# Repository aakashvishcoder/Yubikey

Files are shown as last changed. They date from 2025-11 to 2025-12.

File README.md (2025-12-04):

# Yubikey

This is my version of a YubiKey, built around the RP2040 microcontroller! It’s a compact, secure authentication device designed to generate one‑time passwords and handle cryptographic operations for two‑factor authentication. This key has several unique features and components (as listed below), and is meant to replicate the core functionality of a hardware security token.

# Features:
- Programmable LED(s)
- USBC Receptacle
- RP2040 Microcontroller
- Stores Password (through firmware)

# How to Use

The switches on the PCB can be used to boot up and reset the microcontroller, and the firmware can be modified to your liking!

# Images:







# Build of Materials (BOM)
| Item | Description | Qty | Product link | Price w/ Tax ($) | Running Total |
|---|---|-----|---|---|---|
| Capacitor | 1uF | 2 | [link](https://jlcpcb.com/partdetail/53938-CL05A105KA5NQNC/C52923) | $0.03 | $0.03 |
| Capacitor | 0.1uF | 4 | [link](https://jlcpcb.com/partdetail/1877-CL05B104KO5NNNC/C1525) | $0.07 | $0.10 |
| Capacitor | 10uF | 1 | [link](https://jlcpcb.com/partdetail/2043-CL10A106MQ8NNNC/C1691) | $0.09 | $0.19 |
| Capacitor | 15pF | 2 | [link](https://jlcpcb.com/partdetail/1914-0402CG150J500NT/C1547) | $0.01 | $0.20 |
| Resistor | 5.1k | 2 | [link](https://jlcpcb.com/partdetail/26648-0402WGF5101TCE/C25905) | $0.01 | $0.21 |
| Resistor | 470 | 1 | [link](https://jlcpcb.com/partdetail/UNIROYAL-0402WGF4700TCE/C25130) | $0.01 | $0.22 |
| Resistor | 4.7k | 2 | [link](https://jlcpcb.com/partdetail/UNIROYAL-0402WGF4701TCE/C25867) | $0.01 | $0.23 |
| Resistor | 10k | 1 | [link](https://jlcpcb.com/partdetail/UNIROYAL-0402WGF1002TCE/C25744) | $0.01 | $0.24 |
| Resistor | 27 | 2 | [link](https://jlcpcb.com/partdetail/UNIROYAL-0402WGF270JTCE/C25100) | $0.01 | $0.25 |
| Resistor | 1k | 1 | [link](https://jlcpcb.com/partdetail/UNIROYAL-0402WGF1001TCE/C11702) | $0.01 | $0.26 |
| SW_Push | Tactile Button | 2 | [link](https://jlcpcb.com/partdetail/XKBConnectivity-TS-1187A-B-A-B/C318884) | $0.42 | $0.68 |
| LED | Indicator LED 0402 | 1 | [link](https://jlcpcb.com/partdetail/Honglitronic-HL-LED0402R/C2290) | $0.02 | $0.70 |
| WS2812B | RGB LED | 1 | [link](https://jlcpcb.com/partdetail/Worldsemi-WS2812B_BT/C2761795) | $0.20 | $0.90 |
| RP2040 | Microcontroller | 1 | [link](https://jlcpcb.com/partdetail/RaspberryPi-RP2040/C2040) | $4.58 | $5.48 |
| USB Receptacle | USB-C 16P | 1 | [link](https://jlcpcb.com/partdetail/Korean_HropartsElec-TYPE_C_31_M12/C165948) | $0.85 | $6.33 |
| ATECC608A | Secure Element | 1 | [link](https://jlcpcb.com/partdetail/MicrochipTech-ATECC608ASSHDA/C148118) | $1.97 | $8.30 |
| W25Q128JVS | Flash Storage | 1 | [link](https://jlcpcb.com/partdetail/WinbondElec-W25Q128JVSIQ/C97521) | $2.67 | $10.97 |
| Crystal | 12MHz 3225 | 1 | [link](https://jlcpcb.com/partdetail/YXC_CrystalOscillators-X322512MSB4SI/C9002) | $0.32 | $11.29 |
| Conn_01x03 | Pin Header 1x3 | 1 | [link](https://jlcpcb.com/partdetail/BOOMELE-BM03B-SRSS-TB/C42431804) | $0.05 | $11.34 |
| Conn_01x20 | 1x20 Pin Headers | 2 | [link](https://jlcpcb.com/partdetail/BOOMELE-BM20B-SRSS-TB/C42431804) | $0.17 | $11.51 |
| Yubikey PCBA | PCBA board assembly | 1 | [link](https://cart.jlcpcb.com/) | $43.94 | $55.45 |

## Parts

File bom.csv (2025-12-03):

Item | Description | Quantity | Product link | Price w/ Tax ($) | Running Total
Capacitor | 1uF | 2 | https://jlcpcb.com/partdetail/53938-CL05A105KA5NQNC/C52923 | $0.03 | $0.03
Capacitor | 0.1uF | 4 | https://jlcpcb.com/partdetail/1877-CL05B104KO5NNNC/C1525 | $0.07 | $0.10
Capacitor | 10uF | 1 | https://jlcpcb.com/partdetail/2043-CL10A106MQ8NNNC/C1691 | $0.09 | $0.19
Capacitor | 15pF | 2 | https://jlcpcb.com/partdetail/1914-0402CG150J500NT/C1547 | $0.01 | $0.20
Resistor | 5.1k | 2 | https://jlcpcb.com/partdetail/26648-0402WGF5101TCE/C25905 | $0.01 | $0.21
Resistor | 470 | 1 | https://jlcpcb.com/partdetail/UNIROYAL-0402WGF4700TCE/C25130 | $0.01 | $0.22
Resistor | 4.7k | 2 | https://jlcpcb.com/partdetail/UNIROYAL-0402WGF4701TCE/C25867 | $0.01 | $0.23
Resistor | 10k | 1 | https://jlcpcb.com/partdetail/UNIROYAL-0402WGF1002TCE/C25744 | $0.01 | $0.24
Resistor | 27 | 2 | https://jlcpcb.com/partdetail/UNIROYAL-0402WGF270JTCE/C25100 | $0.01 | $0.25
Resistor | 1k | 1 | https://jlcpcb.com/partdetail/UNIROYAL-0402WGF1001TCE/C11702 | $0.01 | $0.26
SW_Push | Tactile Button | 2 | https://jlcpcb.com/partdetail/XKBConnectivity-TS-1187A-B-A-B/C318884 | $0.42 | $0.68
LED | Indicator LED 0402 | 1 | https://jlcpcb.com/partdetail/Honglitronic-HL-LED0402R/C2290 | $0.02 | $0.70
WS2812B | RGB LED | 1 | https://jlcpcb.com/partdetail/Worldsemi-WS2812B_BT/C2761795 | $0.20 | $0.90
RP2040 | Microcontroller | 1 | https://jlcpcb.com/partdetail/RaspberryPi-RP2040/C2040 | $4.58 | $5.48
USB Receptacle | USB-C 16P | 1 | https://jlcpcb.com/partdetail/Korean_HropartsElec-TYPE_C_31_M12/C165948 | $0.85 | $6.33
ATECC608A | Secure Element | 1 | https://jlcpcb.com/partdetail/MicrochipTech-ATECC608ASSHDA/C148118 | $1.97 | $8.30
W25Q128JVS | Flash Storage | 1 | https://jlcpcb.com/partdetail/WinbondElec-W25Q128JVSIQ/C97521 | $2.67 | $10.97
Crystal | 12MHz 3225 | 1 | https://jlcpcb.com/partdetail/YXC_CrystalOscillators-X322512MSB4SI/C9002 | $0.32 | $11.29
Conn_01x03 | Pin Header 1x3 | 1 | https://jlcpcb.com/partdetail/BOOMELE-BM03B-SRSS-TB/C42431804 | $0.05 | $11.34
Conn_01x20 | 1x20 Pin Headers | 2 | https://jlcpcb.com/partdetail/BOOMELE-BM20B-SRSS-TB/C42431804 | $0.17 | $11.51
Yubikey PCBA | PCBA board assembly | 1 | N/A (https://cart.jlcpcb.com/) | $43.94 | $55.45

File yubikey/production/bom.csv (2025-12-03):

Designator | Footprint | Quantity | Value | LCSC Part #
C1,C6 | 0402 | 2 | 1uF | C1523
C2,C3,C4,C9 | 0402 | 4 | 100nF | C1525
C5 | 0402 | 1 | 10uF | C15525
C7,C8 | 0402 | 2 | 15pF | C1547
D1 | 0402 | 1 | LED | C2290
J1 | USB_C_Receptacle_GCT_USB4105-xx-A_16P_TopMnt_Horizontal | 1 | USB_C_Receptacle_USB2.0_16P | C165948
R1,R2 | 0402 | 2 | 5.1k | C25905
R3 | 0402 | 1 | 470 | C25130
R4,R5 | 0402 | 2 | 4.7k | C25867
R6 | 0402 | 1 | 10k | C25804
R7,R8 | 0402 | 2 | 27 | C23154
R9 | 0402 | 1 | 1k | C21190
SW1 | SW_Tactile_SPST_NO_Straight_CK_PTS636Sx25SMTRLFS | 1 | BOOTSEC | C318884
SW2 | SW_Tactile_SPST_NO_Straight_CK_PTS636Sx25SMTRLFS | 1 | RESET | C318884
U1 | SOIC-8_3.9x4.9mm_P1.27mm | 1 | ATECC608A-SSHDA | C148118
U2 | QFN-56-1EP_7x7mm_P0.4mm_EP3.2x3.2mm | 1 | RP2040 | C2040
U3 | SOIC-8_5.3x5.3mm_P1.27mm | 1 | W25Q128JVS | C97521
Y1 | Crystal_SMD_Abracon_ABM8G-4Pin_3.2x2.5mm | 1 | 12MHz | C9005

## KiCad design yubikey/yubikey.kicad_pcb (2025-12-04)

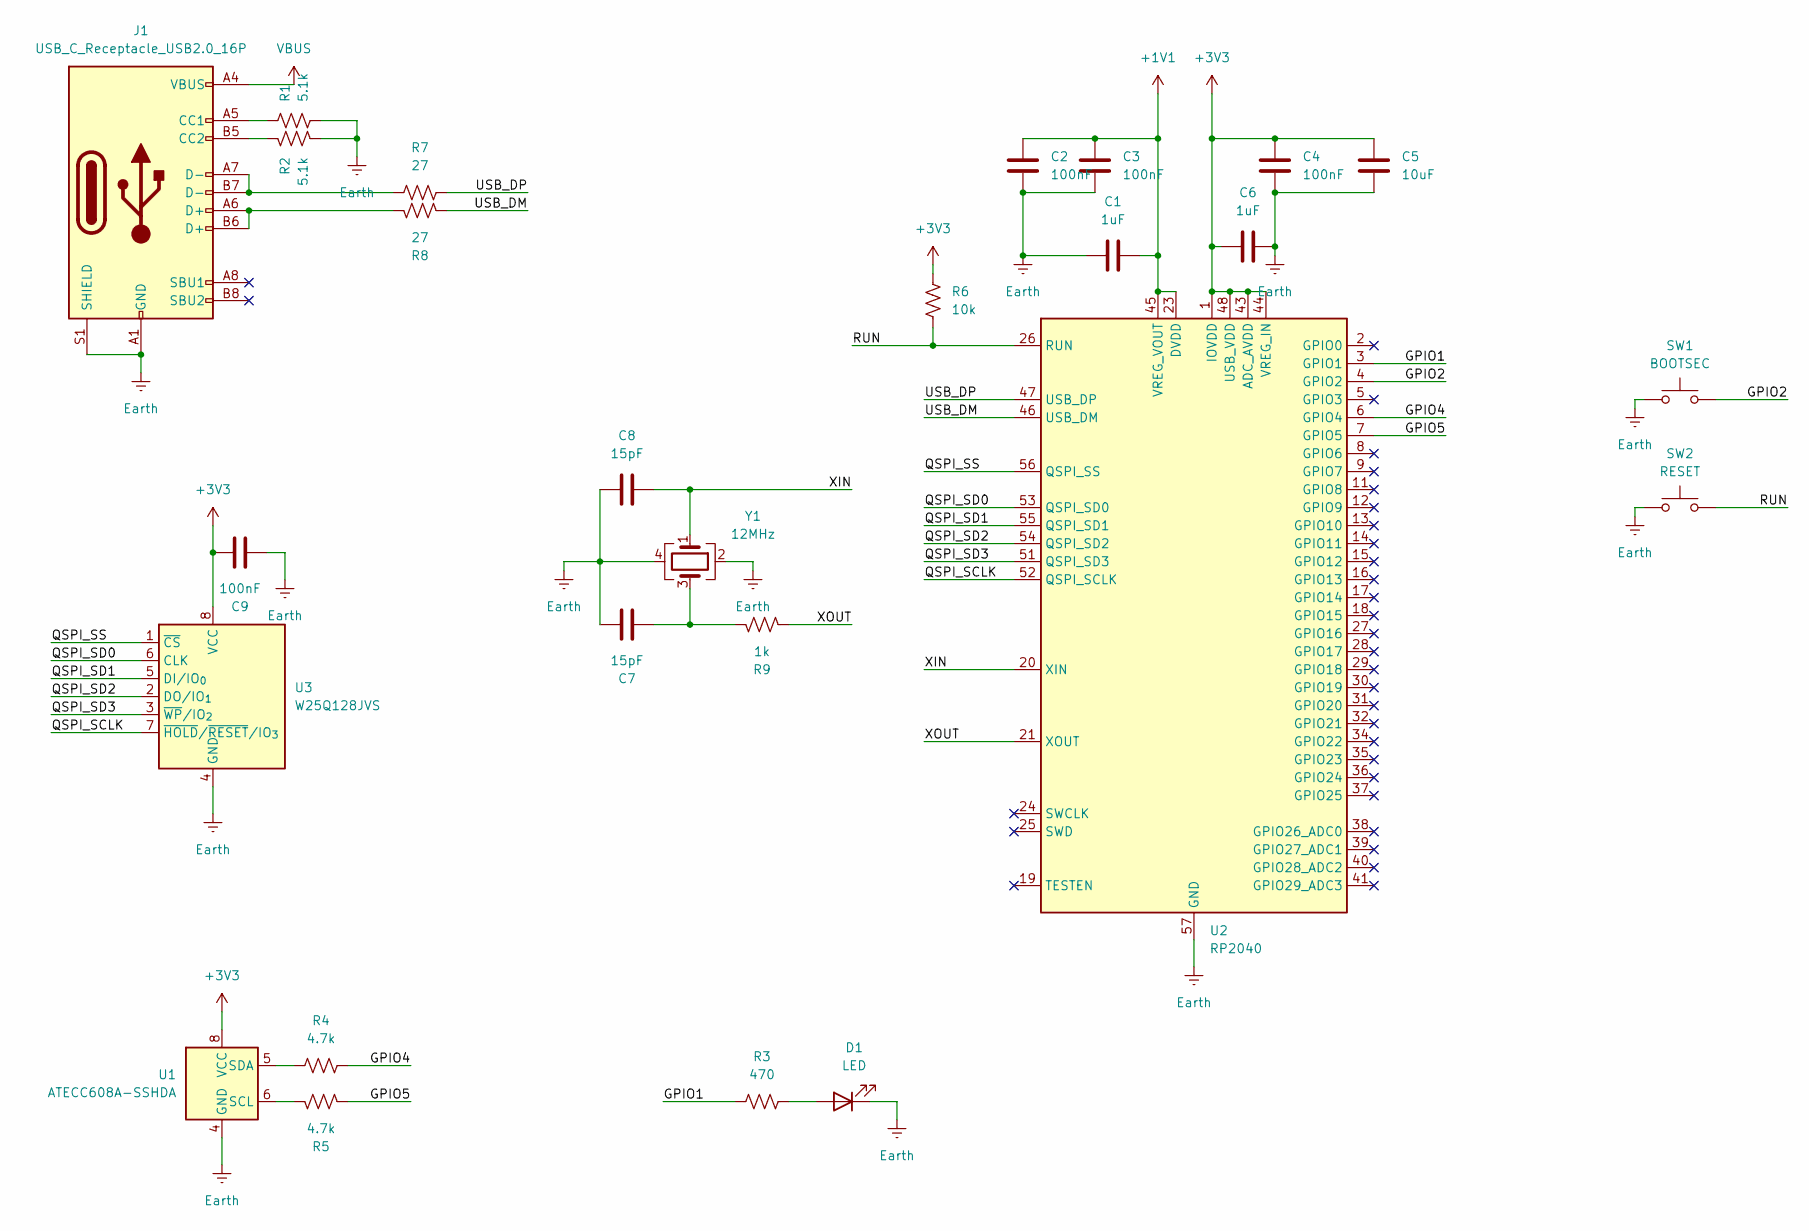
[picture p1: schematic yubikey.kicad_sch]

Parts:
C1, C6: 1uF; C_0402_1005Metric
C2, C3, C4, C9: 100nF; C_0402_1005Metric
C5: 10uF; C_0402_1005Metric
C7, C8: 15pF; C_0402_1005Metric
D1: LED; C_0402_1005Metric
J1: USB_C_Receptacle_USB2.0_16P; USB_C_Receptacle_GCT_USB4105-xx-A_16P_TopMnt_Horizontal
R1, R2: 5.1k; L_0402_1005Metric
R3: 470; L_0402_1005Metric
R4, R5: 4.7k; L_0402_1005Metric
R6: 10k; L_0402_1005Metric
R7, R8: 27; L_0402_1005Metric
R9: 1k; L_0402_1005Metric
SW1: BOOTSEC; SW_Tactile_SPST_NO_Straight_CK_PTS636Sx25SMTRLFS
SW2: RESET; SW_Tactile_SPST_NO_Straight_CK_PTS636Sx25SMTRLFS
U1: ATECC608A-SSHDA; SOIC-8_3.9x4.9mm_P1.27mm
U2: RP2040; QFN-56-1EP_7x7mm_P0.4mm_EP3.2x3.2mm
U3: W25Q128JVS; SOIC-8_5.3x5.3mm_P1.27mm
Y1: 12MHz; Crystal_SMD_Abracon_ABM8G-4Pin_3.2x2.5mm

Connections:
+1V1: C1.2, C2.2, C3.2, U2.23 (DVDD), U2.45 (VREG_VOUT), U2.50 (DVDD)
+3V3: C4.2, C5.2, C6.2, C9.1, R6.1, U1.8 (VCC), U2.1 (IOVDD), U2.10 (IOVDD), U2.22 (IOVDD), U2.33 (IOVDD), U2.42 (IOVDD), U2.43 (ADC_AVDD), U2.44 (VREG_IN), U2.48 (USB_VDD), U2.49 (IOVDD), U3.8 (VCC)
/GPIO1: R3.1, U2.3 (GPIO1)
/GPIO2: SW1.2, U2.4 (GPIO2)
/GPIO4: R4.1, U2.6 (GPIO4)
/GPIO5: R5.1, U2.7 (GPIO5)
/QSPI_SCLK: U2.52 (QSPI_SCLK), U3.7 (~HOLD/~RESET/IO_{3})
/QSPI_SD0: U2.53 (QSPI_SD0), U3.6 (CLK)
/QSPI_SD1: U2.55 (QSPI_SD1), U3.5 (DI/IO_{0})
/QSPI_SD2: U2.54 (QSPI_SD2), U3.2 (DO/IO_{1})
/QSPI_SD3: U2.51 (QSPI_SD3), U3.3 (~WP/IO_{2})
/QSPI_SS: U2.56 (QSPI_SS), U3.1 (~CS)
/RUN: R6.2, SW2.2, U2.26 (RUN)
/USB_DM: R8.2, U2.46 (USB_DM)
/USB_DP: R7.2, U2.47 (USB_DP)
/XIN: C8.2, U2.20 (XIN), Y1.1
/XOUT: R9.2, U2.21 (XOUT)
Earth: C1.1, C2.1, C3.1, C4.1, C5.1, C6.1, C7.1, C8.1, C9.2, D1.1 (K), J1.A1 (GND), J1.A12 (GND), J1.B1 (GND), J1.B12 (GND), J1.S1 (SHIELD), R1.2, R2.2, SW1.1, SW2.1, U1.4 (GND), U2.57 (GND), U3.4 (GND), Y1.2, Y1.4
unnamed: C7.2, R9.1, Y1.3
unnamed: D1.2 (A), R3.2
unnamed: J1.A5 (CC1), R1.1
unnamed: J1.B5 (CC2), R2.1
unnamed: J1.A6 (D+), J1.B6 (D+), R8.1
unnamed: J1.A7 (D-), J1.B7 (D-), R7.1
unnamed: R5.2, U1.6 (SCL)
unnamed: R4.2, U1.5 (SDA)
VBUS: J1.A4 (VBUS), J1.A9 (VBUS), J1.B4 (VBUS), J1.B9 (VBUS)

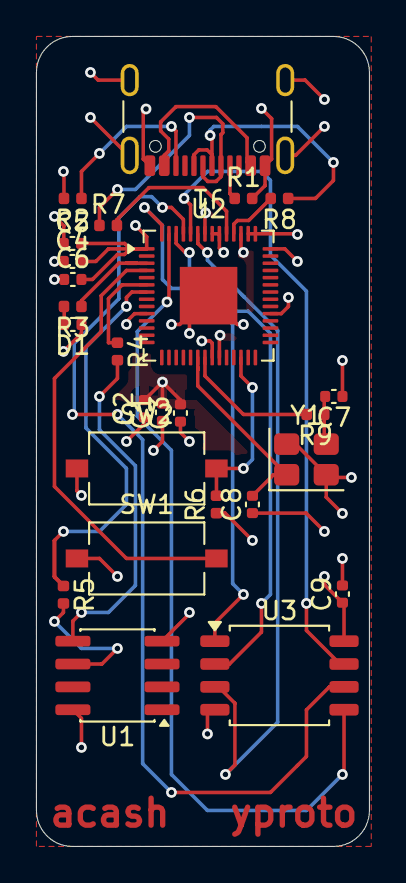
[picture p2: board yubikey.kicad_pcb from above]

Board: 4 copper layers, 18.5 x 45.0 mm, 26 parts (0 on the bottom side), 27 nets.

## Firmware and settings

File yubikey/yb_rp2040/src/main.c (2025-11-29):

#include "pico/stdlib.h"
#include "tusb.h"
#include "atecc_driver.h"
#include "u2f_transport.h"

static void usb_init(void) {
    tusb_init();
}

int main() {
    stdio_init_all();
    usb_init();
    u2f_transport_init();

    if (!atecc_init()) {
        printf("ATECC608A init failed");
        gpio_init(PICO_DEFAULT_LED_PIN);
        gpio_set_dir(PICO_DEFAULT_LED_PIN, true);
        while (true) {
            gpio_put(PICO_DEFAULT_LED_PIN, 1);
            sleep_ms(200);
            gpio_put(PICO_DEFAULT_LED_PIN, 0);
            sleep_ms(200);
        }
    }

    while (true) {
        tud_task();
        tight_loop_contents();
    }
}

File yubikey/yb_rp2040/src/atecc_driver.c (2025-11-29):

#include "atecc_driver.h"
#include "pico/stdlib.h"
#include "hardware/i2c.h"
#include <string.h>

#define ATECC_I2C i2c0
#define ATECC_SDA_PIN 4
#define ATECC_SCL_PIN 5
#define ATECC_ADDR 0x60

static void i2c_init_atecc(void) {
    i2c_init(ATECC_I2C, 400 * 1000);
    gpio_set_function(ATECC_SDA_PIN, GPIO_FUNC_I2C);
    gpio_set_function(ATECC_SCL_PIN, GPIO_FUNC_I2C);
    gpio_pull_up(ATECC_SDA_PIN);
    gpio_pull_up(ATECC_SCL_PIN);
}

bool atecc_init(void) {
    i2c_init_atecc();
    sleep_ms(10);
    return true;
}

bool atecc_get_serial(uint8_t serial[9]) {
    memset(serial, 0, 9);
    return true;
}

bool atecc_get_attestation_key(uint8_t pubkey[64]) {
    memset(pubkey, 0, 64);
    return true;
}

bool atecc_sign(uint8_t slot, const uint8_t *msg32, uint8_t sig64[64]) {
    memset(sig64, 0, 64);
    return true;
}

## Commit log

2025-11-29 completed yubikey
    [yubikey.kicad_pcb, yubikey.kicad_sch]
2025-11-29 added some more pictures to the pcb
    [yubikey.kicad_pcb]
2025-12-01 quick few updates
    [yubikey.kicad_pcb, yubikey.kicad_sch]
2025-12-01 Update BOM with pricing information
    Added price and total columns to the BOM section.
2025-12-03 fixed gitignore, made gerber and production files, finished the bom
    [bom.csv, designators.csv, positions.csv]
2025-12-03 fixed bom
    [bom.csv, yubikey.kicad_pcb]
2025-12-03 forgot to comit
    [bom.csv]
2025-12-03 Revise BOM with detailed item information
    Updated the Bill of Materials (BOM) section with item descriptions, quantities, product links, and prices.
2025-12-03 moved some files arounjd
    [bom.csv, yubikey.csv]
2025-12-04 fixed some issues with pcb
    [yubikey.kicad_pcb]
